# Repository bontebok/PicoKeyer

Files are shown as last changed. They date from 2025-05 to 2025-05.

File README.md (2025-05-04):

# PicoKeyer
PicoKeyer is a CW keyer for the [Raspberry Pi Pico](https://www.raspberrypi.com/products/raspberry-pi-pico/) that let's you to practice CW (morse code) in Desktop or Mobile browser that supports the [Web MIDI API](https://developer.mozilla.org/en-US/docs/Web/API/MIDIAccess#browser_compatibility). PicoKeyer has many configurable options, including the key type, words per minutes rate, LED/GPIO output, MIDI parameters; all within your browser. The PicoKeyer also provides a USB MIDI interface that enables you to use any MIDI app of your choice to record or listen to your CW.

[PicoKeyer Browser App](https://bontebok.github.io/PicoKeyer/)

picokeyer

## Getting Started
You will need a Raspberry Pi Pico based on the RP2040 chip and a CW key (straight or paddles). The Pi Pico is available in a variety of configurations, any of them should work. If you do not already have a Pi Pico, I recommend picking up either an original Raspberry Pi Pico or a Waveshare RP2040-Zero board as I have tested both. You can find the original [Raspberry Pi Pico](https://www.raspberrypi.com/products/raspberry-pi-pico/), [Waveshare RP2040-Zero](https://www.waveshare.com/rp2040-zero.htm), or a clone from $3-10/ea on Amazon, Aliexpress, or at retailers like Micro Center. If you want to use the case design included in the [waveshare_rp2040_case](https://github.com/bontebok/PicoKeyer?tab=readme-ov-file#waveshare-rp2040-zero-build) directory, you will need a Waveshare RP2040-Zero or clone.

In addition to the Pi Pico, you will also need a way to connnect your RP2040 to your key. Most keys use a standard 3.5MM (1/8") stereo jack, however bare wires will also work fine. If you want to use the standard 3.5MM jack, I recommend the Lsgoodcare headphone jacks in the link below.

Amazon Links (non-affiliate)
* [Raspberry Pi Pico (Quantity 2) $10](https://www.amazon.com/Raspberry-Development-Dual-core-Processor-Integrated/dp/B0CPMBRVDX/)
* [Waveshare RP2040 Zero (Quantity 3) $20](https://www.amazon.com/RP2040-Zero-High-Performance-Microcontroller-Castellated-Boards-3pcs/dp/B0B2ZFGSMD/)
* [Lsgoodcare 10PCS 3.5MM Female Headphone Stereo Jack](https://www.amazon.com/dp/B01CVGD4UI)

## Assembly
The Raspberry Pi Pico comes with breadboard-friendly header pins, so it technically is possible that you could assemble a PicoKeyer using breadboard. However, I recommend that you solder a 3.5MM jack or a 3.5MM headphone-style cable directly to the Pi Pico as this will give you the best result. If you have basic soldering skills, assembly should be a breeze.



### Straight Key
The simplest configuration is a straight key as only two wires are needed. The common (ground) of the key should be wired to one of the Raspberry Pi Pico ground pins, while the other contact needs to be wired to any available GPIO pin. Take note of the GPIO pin number as you will need to set that pin in the settings.

| Pi Pico Pin | 3.5MM TRS Jack Pin |
| --- | --- |
| GND | Pin 1 / (sleeve) |
| Any GPIO | Pin 2 / (tip) |

### Paddles
Three wires are needed to connect a paddle key to the PicoKeyer. The common (ground) of the key should be wired to one of the Raspberry Pi Pico ground pins, while the other two contacts (left and right paddle) need to be wired to any free GPIO pin. Take note of each GPIO pin number as you will need to set that pin in the settings.

| Pi Pico Pin | 3.5MM TRS Jack Pin |
| --- | --- |
| GND | Pin 1 / (sleeve) |
| Any GPIO | Pin 2 / (tip) |
| Any GPIO | Pin 3 / (ring) |

## Firmware Installation
Head over to [Releases](https://github.com/bontebok/PicoKeyer/releases) and download the latest PicoKeyer.uf2 firmware. Plug in your Raspberry Pi Pico and open the RPI-RP2 drive. If the drive does not appear, hold down the Boot button on the Pi Pico before plugging it it. Copy the PicoKeyer.uf2 file to the RPI-RP2 drive. Once the firmware has finished copying, open the [PicoKeyer Browser App](https://bontebok.github.io/PicoKeyer/) in a browser that supports the Web MIDI API to configure your PicoKeyer.

## PicoKeyer Web Application
The [PicoKeyer Browser App](https://bontebok.github.io/PicoKeyer/) provides a USB MIDI interface and allows you to directly configure the PicoKeyer from your browser. You will need a browser that supports the [Web MIDI API](https://developer.mozilla.org/en-US/docs/Web/API/MIDIAccess#browser_compatibility) (note: Safari does not support the Web MIDI API). Plug in your PicoKeyer to a free USB port and open the PicoKeyer Browser App. The app will prompt you for permission to access MIDI Devices, once allowed the application should automatically detect the PicoKeyer. If detection was successful, you will see the Settings button.



Click on the Settings button to begin configuring your PicoKeyer. Choose the key type to continue.



Configure the values for the Words Per Minute, Dit Paddle GPIO, Dah Paddle GPIO. All other values can be left default. (note: Other GPIO pin modes are supported, but if you have connected your common wire to GND on the Pi Pico, you will want to leave it on Pull Up mode)



Once you are satisfied with your options, you can press Apply to test. If successful, pressing your key should produce a visual indicator in the black box. You can enable sound by clicking on the slider to hear a CW tone. If you are satisfied, press Save to save the settings to your Pi Pico's NVRAM so the settings will persist between reboots.

## Waveshare RP2040-Zero Build
My favorite Pi Pico is the [Waveshare RP2040-Zero](https://www.waveshare.com/rp2040-zero.htm), it's a minature version of the full size Raspberry Pi Pico making it great for compact builds with no compromises. The RP2040-Zero comes standard with USB-C and an onboard addressable RGB LED. If purchased in bulk, the RP2040-Zero typically sell for about $2 each which makes them an ever better bargain than the Raspberry Pi Pico. For the PicoKeyer project, I have designed a custom case and included the STLs in the [waveshare_rp2040_case](https://github.com/bontebok/PicoKeyer/tree/main/waveshare_rp2040_case) directory.

The assembly is pretty simple, just find two available GPIO pins (I recommend GPIO 3 and GPIO 29) and solder to a 3.5MM female jack (linked above). Before soldering, ensure that the jack is facing away from the USB-C port.



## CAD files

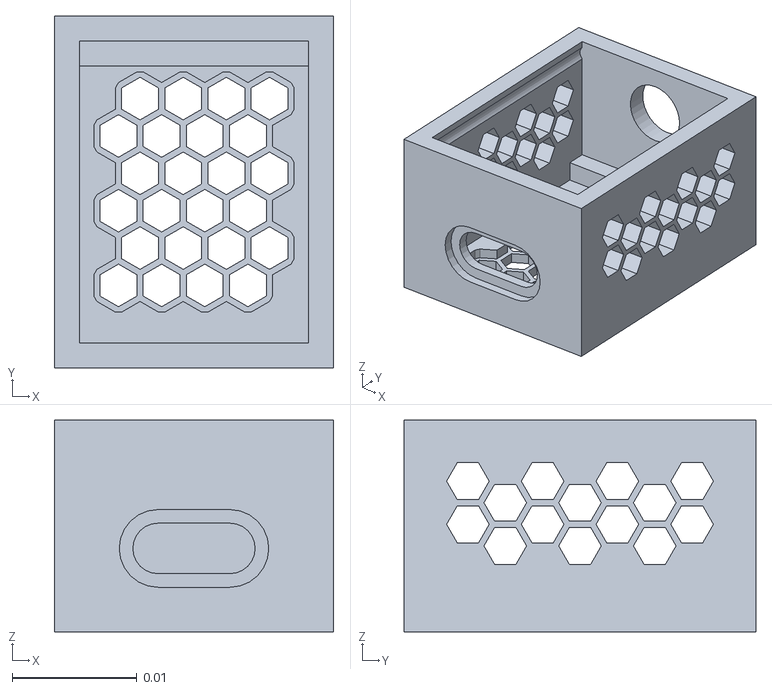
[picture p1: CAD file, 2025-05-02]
waveshare_rp2040_case/PicoKeyer_case.stl
0.0224 x 0.0283 x 0.017

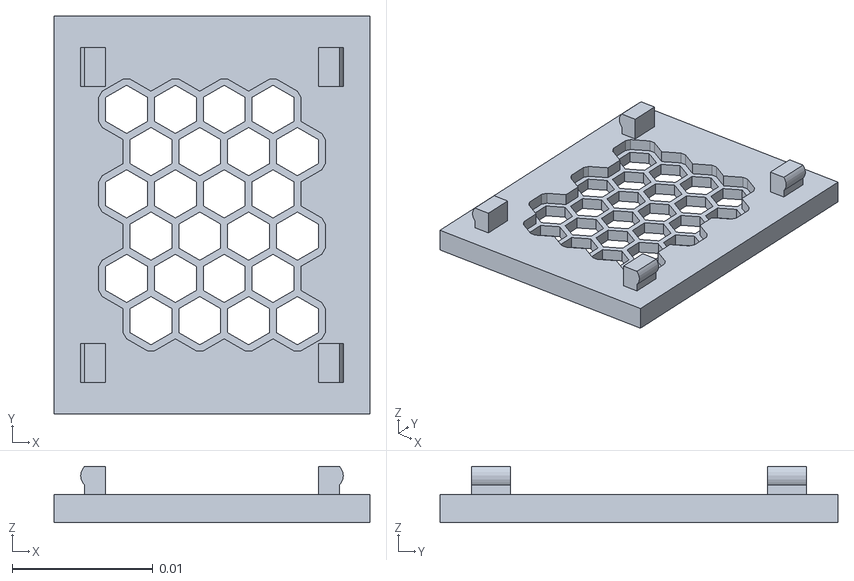
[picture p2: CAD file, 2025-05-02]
waveshare_rp2040_case/PicoKeyer_lid.stl
0.0224 x 0.0283 x 0.004

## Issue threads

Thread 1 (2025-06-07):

Visual confirmation for configuration settings applying and saving on PicoKeyer Web App

TheSpecterLemon, 2025-06-07:
// What //

Web App configuration page

// Issue //

There is no visual confirmation when configuration settings from the web app are applied and saved to the Pico hardware. Users would need to rely on resetting or plugging the Pico to verify settings.

// Solution //
Add an indicator when settings are successfully and unsuccessfully applied.
Applied success: "Settings successfully applied"
Saved success: "Settings successfully saved"
Applied fail: "Settings were not able to be applied"
Saved fail: "Settings were not able to be saved"

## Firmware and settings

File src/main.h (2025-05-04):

#ifndef MAIN_H
#define MAIN_H

#include <Arduino.h>

// Firmware compatability
#define VERSION 0x2

// USB MIDI Config
#define MANUFACTURER "bontebok"
#define PRODUCT "PicoKeyer"
#define SYSEX_HEADER {0xF0, 0x7D}
#define SYSEX_FOOTER 0xF7

// Define default settings
#define DEFAULT_WPM INTTOFLOATSCALAR * 12 // Fixed point value (WPM / INTTOFLOATSCALAR), allows for half/quarter timings if desired
#define DEFAULT_KEYMODE keyMode_t::KEY_NONE
#define DEFAULT_PINMODE PinMode::INPUT_PULLUP
#define DEFAULT_LEDMODE ledMode_t::LED_DISABLED
#define DEFAULT_OUTPUTMODE gpioOutputMode_t::OUTPUT_DISABLED
#define DEFAULT_GPIO_OUTPUT 14
#define DEFAULT_GPIO_DITPADDLE 3
#define DEFAULT_GPIO_DAHPADDLE 29
#define DEFAULT_GPIO_STRAIGHT 3
#define DEFAULT_GPIO_NORMALDLED 25
#define DEFAULT_GPIO_RGBLED 16
#define DEFAULT_MIDI_NOTE 77
#define DEFAULT_MIDI_CHANNEL 1
#define DEFAULT_MIDI_VOLUME 40

// RGB LED Settings
#define NEOPIXELTYPE NEO_GRB + NEO_KHZ800
#define NEOPIXELBRIGHTNESS 127

// SysEx Commands
#define CMD_GET_VERSION 0
#define CMD_GET_CONFIG 1
#define CMD_SET_CONFIG 2
#define CMD_SAVE_CONFIG 3
#define CMD_REBOOT 4
#define CMD_BOOTSEL 5

// Byte array SysEx buffer
#define MAX_SYSEX_LENGTH 32

// WS2812 LED setup
#define NUM_LEDS 1

// Timing constants (in milliseconds)
#define DEBOUNCE_TIME 10 // Debounce period in ms

// Int scalar value
#define INTTOFLOATSCALAR 100.0

// Settings file path
#define SETTINGS_FILE "/settings.bin"

// Key Modes
enum keyMode_t : uint8_t
{
    KEY_NONE,
    KEY_STRAIGHT,
    KEY_PADDLES
};

// LED Modes
enum ledMode_t : uint8_t
{
    LED_DISABLED,
    LED_NORMAL,
    LED_RGB
};

// GPIO Output Mode
enum gpioOutputMode_t : uint8_t
{
    OUTPUT_DISABLED,
    OUTPUT_NORMAL,
    OUTPUT_INVERSED
};

// GPIO pins
struct GPIO_t
{
    uint8_t normalLED;
    uint8_t rgbLED;
    uint8_t output;
    uint8_t ditPaddle;
    uint8_t dahPaddle;
    uint8_t straightKey;
};

// Timing values for iambic key
struct Timings_t
{
    uint dit;
    uint dah;
    uint gap;
};

// Menu structure
struct Settings_t
{
    uint16_t version;
    Timings_t timings;
    GPIO_t gpio;
    uint16_t wpm;
    keyMode_t keyMode;
    PinMode pinMode;
    ledMode_t ledMode;
    gpioOutputMode_t gpioOutputMode;
    uint8_t note;
    uint8_t channel;
    uint8_t volume;
};

// Paddle state tracking
struct PaddleState_t
{
    bool currentState;       // Current debounced state
    bool lastReading;        // Last raw reading
    uint32_t lastChangeTime; // Time of last state change
};

// Output state
enum OutputState_t : uint8_t
{
    IDLE,
    OUTPUT_ON,
    OUTPUT_OFF
};

// Next output
enum NextElement_t : uint8_t
{
    NONE,
    DIT,
    DAH
};

#endif

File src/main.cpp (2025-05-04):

#include <Arduino.h>
#include <Adafruit_NeoPixel.h>
#include <Control_Surface.h>
#include <Adafruit_TinyUSB.h>
#include <BitPacker.hpp>
#include "main.h"
#include "nvram.h"

Settings_t settings;

// Sraight Key/Paddle variables
PaddleState_t straightKey = {false, false, 0};
PaddleState_t ditPaddle = {false, false, 0};
PaddleState_t dahPaddle = {false, false, 0};

OutputState_t currentState = OutputState_t::IDLE;
uint32_t stateEndTime = 0;
bool lastWasDit = false; // Tracks whether last output was a dit
NextElement_t nextElement = NextElement_t::NONE;

// SysEx tokens
const uint8_t sysex_header[] = SYSEX_HEADER;
const uint8_t sysex_footer = SYSEX_FOOTER;
uint8_t sysExBuffer[MAX_SYSEX_LENGTH];
uint8_t sysExLength = 0;

// Adafruit_NeoPixel strip(1, 16, NEO_GRB + NEO_KHZ800);
Adafruit_NeoPixel *strip = nullptr;

// Control Surface variables
USBMIDI_Interface midi;
MIDIAddress address;

/** Clear MIDI send and reset inputs for key GPIOs */
void cleanUpKey()
{
  if (currentState == OutputState_t::OUTPUT_ON)
  {
    // Currently sending, need to stop and turn off the LED
    midi.sendNoteOff(address, settings.volume);
    currentState = OutputState_t::IDLE;
  }

  // Cleanup current Key
  if (settings.keyMode == keyMode_t::KEY_STRAIGHT)
  {
    pinMode(settings.gpio.straightKey, INPUT); // Reset input pin
  }
  else if (settings.keyMode == keyMode_t::KEY_PADDLES)
  {
    // Default to normal Input for pins
    pinMode(settings.gpio.ditPaddle, INPUT); // Reset input pin
    pinMode(settings.gpio.dahPaddle, INPUT); // Reset input pin
  }
}

/** Reset GPIO output, if enabled */
void cleanUpOutput()
{
  if (settings.gpioOutputMode == gpioOutputMode_t::OUTPUT_DISABLED)
    return;

  // Turn switch GPIO back to input
  pinMode(settings.gpio.output, INPUT);
}

/** Configures the GPIO Output */
void setupOutput()
{
  if (settings.gpioOutputMode != gpioOutputMode_t::OUTPUT_DISABLED)
  {
    PinStatus initialState = (settings.gpioOutputMode == gpioOutputMode_t::OUTPUT_NORMAL) ? LOW : HIGH;
    pinMode(settings.gpio.output, OUTPUT);
    digitalWrite(settings.gpio.normalLED, initialState); // Set initial output
  }
}

/** Turns the GPIO output on or off */
void setOutput(bool state)
{
  if (settings.gpioOutputMode == gpioOutputMode_t::OUTPUT_DISABLED)
    return;

  bool setState = (settings.gpioOutputMode == gpioOutputMode_t::OUTPUT_NORMAL) ? state : !state;

  PinStatus outputState = (setState) ? HIGH : LOW;

  digitalWrite(settings.gpio.output, outputState);
}

/** Turns the LED on or off */
void setLed(bool state)
{
  if (settings.ledMode == ledMode_t::LED_NORMAL)
  {
    digitalWrite(settings.gpio.normalLED, state ? HIGH : LOW); // On or off
  }
  else if (settings.ledMode == ledMode_t::LED_RGB)
  {
    strip->setPixelColor(0, state ? strip->Color(255, 0, 0) : strip->Color(0, 0, 0)); // Red or off
    strip->show();
  }
}

/** Sets or updates the word per minute timings for paddle mode */
void setupWPM()
{
  settings.timings.dit = (INTTOFLOATSCALAR * 1200) / settings.wpm;
  settings.timings.dah = settings.timings.dit * 3;
  settings.timings.gap = settings.timings.dit;
}

/** Sets or updates the channel, note, and volume details for the MIDI output */
void setupMidi()
{
  address = MIDIAddress(settings.note, Channel(settings.channel - 1));
}

/** Configures the key mode and GPIO pins */
void setupKey()
{
  if (settings.keyMode == keyMode_t::KEY_STRAIGHT)
  {
    pinMode(settings.gpio.straightKey, settings.pinMode);
  }
  else if (settings.keyMode == keyMode_t::KEY_PADDLES)
  {
    pinMode(settings.gpio.ditPaddle, settings.pinMode);
    pinMode(settings.gpio.dahPaddle, settings.pinMode);
  }
}

/** Turn off LED and reset input or deactivate */
void cleanUpLED()
{
  // Cleanup current LED
  if (settings.ledMode == ledMode_t::LED_NORMAL)
  {
    // Turn off onboard LED and reset pin
    digitalWrite(settings.gpio.normalLED, LOW);
    pinMode(settings.gpio.normalLED, INPUT);
  }
  else if (settings.ledMode == ledMode_t::LED_RGB)
  {
    strip->clear(); // Set all pixels to off
    strip->show();  // Update to show off state
  }
}

/** Configures the LED */
void setupLed()
{
  if (settings.ledMode == ledMode_t::LED_NORMAL)
  {
    pinMode(settings.gpio.normalLED, OUTPUT);
    digitalWrite(settings.gpio.normalLED, LOW); // Start with LED off
  }
  else if (settings.ledMode == ledMode_t::LED_RGB)
  {
    if (strip == nullptr)
    {
      strip = new Adafruit_NeoPixel(NUM_LEDS, settings.gpio.rgbLED, NEOPIXELTYPE);
      strip->begin();
    }

    strip->clear(); // Set all pixels to off
    strip->show();
    strip->setBrightness(NEOPIXELBRIGHTNESS);
  }
}

/** Encode firmware version for sending over SysEx */
void encodeVersion(const uint16_t version, uint8_t *out, uint8_t &outSize)
{
  BitPacker packer(32);

  packer.addField(version & 0xFFFF, 16);
  packer.pack7Bit(out, outSize);
}

/** Send current configuration as SysEx */
void sendVersion()
{
  uint8_t packedSize;

  sysExLength = sizeof(sysex_header);

  memcpy(sysExBuffer, sysex_header, sysExLength);
  sysExBuffer[sysExLength++] = CMD_GET_VERSION;

  encodeVersion(VERSION, &sysExBuffer[sysExLength], packedSize);

  sysExLength += packedSize;
  sysExBuffer[sysExLength++] = SYSEX_FOOTER;

  // Send SysEx
  midi.sendSysEx(sysExBuffer, sysExLength, address.getCableNumber());
}

/** Encode Config struct into a contiguous 7-bit buffer */
void encodeConfig(const Settings_t &settings, uint8_t *out, uint8_t &outSize)
{
  BitPacker packer(MAX_SYSEX_LENGTH * 8);

  // Add fields in MSB-to-LSB order
  packer.addField(settings.keyMode & 0x3, 2);
  packer.addField(settings.pinMode & 0x3, 2);
  packer.addField(settings.ledMode & 0x3, 2);
  packer.addField(settings.gpioOutputMode & 0x3, 2);
  packer.addField(settings.gpio.output & 0x7F, 7);
  packer.addField(settings.gpio.normalLED & 0x7F, 7);
  packer.addField(settings.gpio.rgbLED & 0x7F, 7);
  packer.addField(settings.gpio.ditPaddle & 0x7F, 7);
  packer.addField(settings.gpio.dahPaddle & 0x7F, 7);
  packer.addField(settings.gpio.straightKey & 0x7F, 7);
  packer.addField(settings.wpm & 0xFFFF, 16);
  packer.addField(settings.channel & 0x7F, 7);
  packer.addField(settings.note & 0x7F, 7);
  packer.addField(settings.volume & 0x7F, 7);
  packer.pack7Bit(out, outSize);
}

/** Encode Config struct into a contiguous 7-bit buffer */
void decodeConfig(Settings_t &settings, const uint8_t *input, uint8_t inputSize)
{
  BitPacker packer(MAX_SYSEX_LENGTH * 8);

  packer.unpack7Bit(input, inputSize);

  settings.keyMode = (keyMode_t)packer.extractField(2);
  settings.pinMode = (PinMode)packer.extractField(2);
  settings.ledMode = (ledMode_t)packer.extractField(2);
  settings.gpioOutputMode = (gpioOutputMode_t)packer.extractField(2);
  settings.gpio.output = packer.extractField(7);
  settings.gpio.normalLED = packer.extractField(7);
  settings.gpio.rgbLED = packer.extractField(7);
  settings.gpio.ditPaddle = packer.extractField(7);
  settings.gpio.dahPaddle = packer.extractField(7);
  settings.gpio.straightKey = packer.extractField(7);
  settings.wpm = (uint16_t)packer.extractField(16);
  settings.channel = packer.extractField(7);
  settings.note = packer.extractField(7);
  settings.volume = packer.extractField(7);
}

/** Send current configuration as SysEx */
void sendConfig()
{
  uint8_t packedSize;

  sysExLength = sizeof(sysex_header);

  memcpy(sysExBuffer, sysex_header, sysExLength);
  sysExBuffer[sysExLength++] = CMD_GET_CONFIG;

  encodeConfig(settings, &sysExBuffer[sysExLength], packedSize);

  sysExLength += packedSize;
  sysExBuffer[sysExLength++] = SYSEX_FOOTER;

  // Send SysEx
  midi.sendSysEx(sysExBuffer, sysExLength, address.getCableNumber());
}

/** Applies received SysEx configuration */
void setConfig(const uint8_t *data, unsigned int length)
{
  // Clear/clean up before applying
  cleanUpKey();
  cleanUpOutput();
  cleanUpLED();

  decodeConfig(settings, &data[sizeof(sysex_header) + 1], length - sizeof(sysex_header) - 1);

  // Apply new config
  setupKey();
  setupOutput();
  setupLed();
  setupWPM();
  setupMidi();
}

/** Handle received SysEx */
void handleSysEx(const uint8_t *data, unsigned int length)
{
  if (length < sizeof(sysex_header) + 2)
    return; // Too short

  // Check SysEx prefix using memcmp
  if (memcmp(data, sysex_header, sizeof(sysex_header)) != 0)
    return; // Invalid prefix

  // Check end byte
  if (data[length - 1] != sysex_footer)
    return; // Missing end byte

  // Extract command (byte after prefix)
  uint8_t command = data[sizeof(sysex_header)];

  switch (command)
  {
  case CMD_GET_VERSION: // Detection request
  {
    sendVersion();
    break;
  }
  case CMD_GET_CONFIG: // Config request
  {
    sendConfig();
    break;
  }
  case CMD_SET_CONFIG: // Config request
  {
    setConfig(data, length);
    break;
  }
  case CMD_SAVE_CONFIG: // Config save request
  {
    setConfig(data, length);
    save(settings);
    break;
  }
  case CMD_REBOOT: // Reboot request
  {
    rp2040.reboot();
    break;
  }
  case CMD_BOOTSEL: // Firmware update mode
  {
    reset_usb_boot(0, 0);
    break;
  }
  }
}

/** Callback for Control Surface to receive a MIDI message */
struct MyMIDI_Callbacks : MIDI_Callbacks
{

  // This callback function is called when a SysEx message is received.
  void onSysExMessage(MIDI_Interface &, SysExMessage sysex) override
  {
    handleSysEx(sysex.data, sysex.length);
  }
} callback{};

/** Updates the debounced state of a key/paddle based on its current reading. */
void updateKeyState(PaddleState_t &paddle, int pin)
{
  bool reading = !digitalRead(pin); // Active low due to pull-up
  if (reading != paddle.lastReading)
  {
    paddle.lastChangeTime = millis();
  }
  if (millis() - paddle.lastChangeTime >= DEBOUNCE_TIME)
  {
    paddle.currentState = reading;
  }
  paddle.lastReading = reading;
}

/** Starts sending a dit or dah by turning on the output and setting the duration. */
void startIambicOutput(bool isDit)
{
  currentState = OutputState_t::OUTPUT_ON;

  // MIDI.sendNoteOn(settings.note, settings.volume, settings.channel);
  midi.sendNoteOn(address, settings.volume);

  stateEndTime = millis() + (isDit ? settings.timings.dit : settings.timings.dah);
  lastWasDit = isDit;
  nextElement = NextElement_t::NONE; // Reset nextElement when starting a new output

  setOutput(true);
  setLed(true);
}

/** Processes the straight key. */
void processStraightKey()
{
  if (straightKey.currentState && currentState == OutputState_t::IDLE)
  {
    midi.sendNoteOn(address, settings.volume);
    setOutput(true);
    setLed(true);
    currentState = OutputState_t::OUTPUT_ON;
  }
  if (!straightKey.currentState && currentState == OutputState_t::OUTPUT_ON)
  {
    midi.sendNoteOff(address, settings.volume);
    setOutput(false);
    setLed(false);
    currentState = OutputState_t::IDLE;
  }
}

/** Processes the iambic keyer state machine. */
void processIambic()
{
  if (currentState == OutputState_t::OUTPUT_ON)
  {
    if (millis() >= stateEndTime)
    {
      midi.sendNoteOff(address, settings.volume);

      currentState = OutputState_t::OUTPUT_OFF;
      stateEndTime = millis() + settings.timings.gap;

      setOutput(false);
      setLed(false);
    }
    else
    {
      // During output, check if the opposite paddle is pressed
      if (lastWasDit && dahPaddle.currentState)
      {
        nextElement = NextElement_t::DAH; // Queue a dah next
      }
      else if (!lastWasDit && ditPaddle.currentState)
      {
        nextElement = NextElement_t::DIT; // Queue a dit next
      }
    }
  }
  else if (currentState == OutputState_t::OUTPUT_OFF)
  {
    if (millis() >= stateEndTime)
    {
      if (nextElement == NextElement_t::DIT)
      {
        startIambicOutput(true); // Send queued dit
      }
      else if (nextElement == NextElement_t::DAH)
      {
        startIambicOutput(false); // Send queued dah
      }
      else if (ditPaddle.currentState)
      {
        startIambicOutput(true); // Send dit if Dit Paddle is pressed
      }
      else if (dahPaddle.currentState)
      {
        startIambicOutput(false); // Send dah if Dah Paddle is pressed
      }
      else
      {
        currentState = OutputState_t::IDLE; // Nothing pressed, go idle
      }
    }
  }
  else if (currentState == OutputState_t::IDLE)
  {
    if (ditPaddle.currentState)
    {
      startIambicOutput(true); // Start with dit
    }
    else if (dahPaddle.currentState)
    {
      startIambicOutput(false); // Start with dah
    }
  }
}

/** Default values from main.h */
void setDefaultSettings()
{
  settings.version = VERSION;
  settings.keyMode = DEFAULT_KEYMODE;
  settings.pinMode = DEFAULT_PINMODE;
  settings.ledMode = DEFAULT_LEDMODE;
  settings.gpioOutputMode = DEFAULT_OUTPUTMODE;
  settings.gpio.output = DEFAULT_GPIO_OUTPUT;
  settings.gpio.normalLED = DEFAULT_GPIO_NORMALDLED;
  settings.gpio.rgbLED = DEFAULT_GPIO_RGBLED;
  settings.gpio.ditPaddle = DEFAULT_GPIO_DITPADDLE;
  settings.gpio.dahPaddle = DEFAULT_GPIO_DAHPADDLE;
  settings.gpio.straightKey = DEFAULT_GPIO_STRAIGHT;
  settings.wpm = DEFAULT_WPM;
  settings.channel = DEFAULT_MIDI_CHANNEL;
  settings.note = DEFAULT_MIDI_NOTE;
  settings.volume = DEFAULT_MIDI_VOLUME;
}

void setup()
{
  //Serial.begin(115200);

  setDefaultSettings();
  init(settings);

  TinyUSBDevice.setManufacturerDescriptor(MANUFACTURER);
  TinyUSBDevice.setProductDescriptor(PRODUCT);
  while (!TinyUSBDevice.mounted())
    delay(1); // Wait for USB to mount

  midi.begin();
  midi.setCallbacks(callback);

  setupKey();
  setupLed();
  setupOutput();
  setupMidi();
  setupWPM();
}

void loop()
{
  midi.update();

  if (settings.keyMode == keyMode_t::KEY_STRAIGHT)
  {
    updateKeyState(straightKey, settings.gpio.straightKey);
    processStraightKey();
  }
  else if (settings.keyMode == keyMode_t::KEY_PADDLES)
  {
    updateKeyState(ditPaddle, settings.gpio.ditPaddle);
    updateKeyState(dahPaddle, settings.gpio.dahPaddle);
    processIambic();
  }
}

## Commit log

2025-05-02 Added 3D print files
    [PicoKeyer_case.stl, PicoKeyer_lid.stl]
2025-05-04 Added new GPIO output mode, bug fixes
    Fixed an issue where pressing Save did not apply the changed configuration. Improved the handling of the RGB LED, added GPIO output capability for keyer. General refactoring and code cleanup.
    [main.cpp, main.h]
